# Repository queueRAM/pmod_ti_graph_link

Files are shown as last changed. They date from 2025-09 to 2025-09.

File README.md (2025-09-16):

# Pmod TI Graph Link breakout board

This repository contains a schematic and PCB layout for a [Pmod](https://digilent.com/reference/pmod/specification)-compatible design that interfaces with TI graphing calculators and peripherals which use the 2.5mm TI graph link connector. The purpose of the board is make it convenient to connect to the calculator DBus without having to solder a cable, provide a convenient pin-out, and to translate the bus voltage to support 3.3V and 5V. The Pmod connectors are very common with FPGA development boards. The board is generic and can be used with any circuit in the 3.3-5V range, such as Arduinos, Raspberry Pis, or homebrew 6502 on breadboards.

The 6-pin Pmod connector supplies VCC, GND, and the two bi-directional tip and ring connections. For each tip and ring there are pull-up resistor, diode, and NPN transistor to allow interfacing with buses of different voltages and out to a 2.5mm stereo TRS jack. The board provisions for an LC low-pass filters for each tip and ring, similar to what is used in the USB silver graph link, TI keyboard, and TI graphing calculators. For debug, the layout provisions for an optional 1x3 header on the DBus side.

## Design

The design optimizes for performance and cost while still being something that
can be hand-soldered. The passives are 0805 or larger, through-hold connectors
were chosen where possible. The diode and transistor are on the smaller pitch,
but were chosen to combine dual components into a single package.
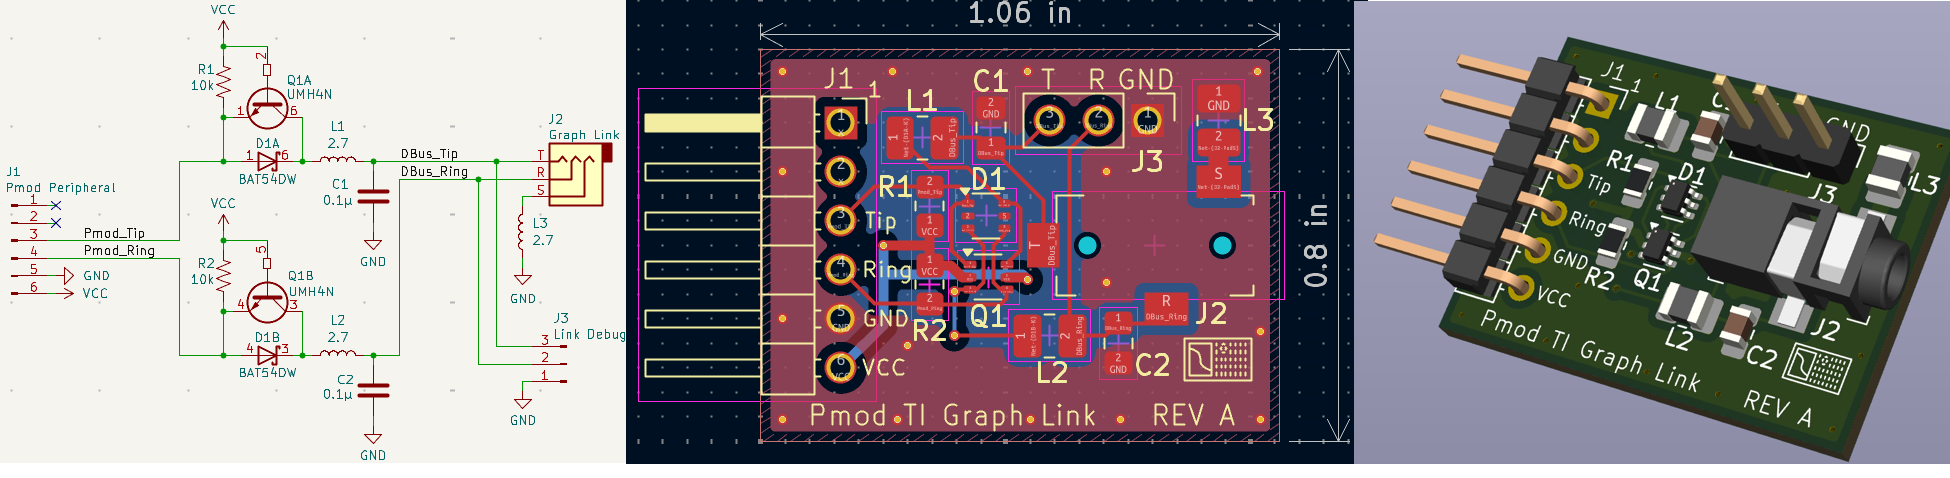
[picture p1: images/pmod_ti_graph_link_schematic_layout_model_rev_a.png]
Pmod TI graph link Rev A


## Bill of Materials (BOM)

REF DES | Footprint | Type            | Manufacturer | Part #           |Qty|
--------|-----------|-----------------|--------------|------------------|---|
J1      | Pmod 0.1" | Pmod Connector  | METZ         | PR20206HBNN      | 1 |
J2      | Custom    | 2.5mm TRS audio | Kycon        | STX-2500-3NTR    | 1 |
J3      | 0.1"      | Debug header*   | METZ         | PR20203VBNN      | 1 |
Q1      | SOT-363   | Bias transistor | Toshiba Semi.| RN1911,LF        | 1 |
D1      | SOT-363   | Schottky diode  | Panjit       | BAT54DW_R1_00001 | 1 |
R1,R2   | 0805      | Pull-up Res.    | YAGEO        | RC0805JR-1310KL  | 2 |
C1,C2   | 0805      | Capacitor*      | YAGEO        | CC0805KRX7R9BB104| 2 |
L1,L2,L3| 1008      | Inductor*       | TDK          | NLV25T-2R7J-EF   | 3 |

(* denotes optional)

 ## Notes

 * [Digilent Pmod specification](https://digilent.com/reference/_media/reference/pmod/pmod-interface-specification-1_3_1.pdf)
 * [TI Graph Link Hardware Protocol](https://www.merthsoft.com/linkguide/hardware.html)
 * [Pmod TI graph link Cemetech forum post](https://www.cemetech.net/forum/viewtopic.php?t=20602)

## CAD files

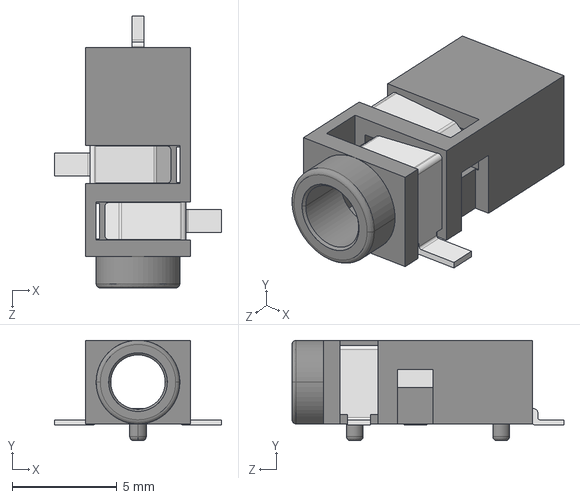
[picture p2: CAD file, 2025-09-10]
3dmodels/STX-2500-3N_rA3.IGS
8.00 x 4.80 x 13.0 mm

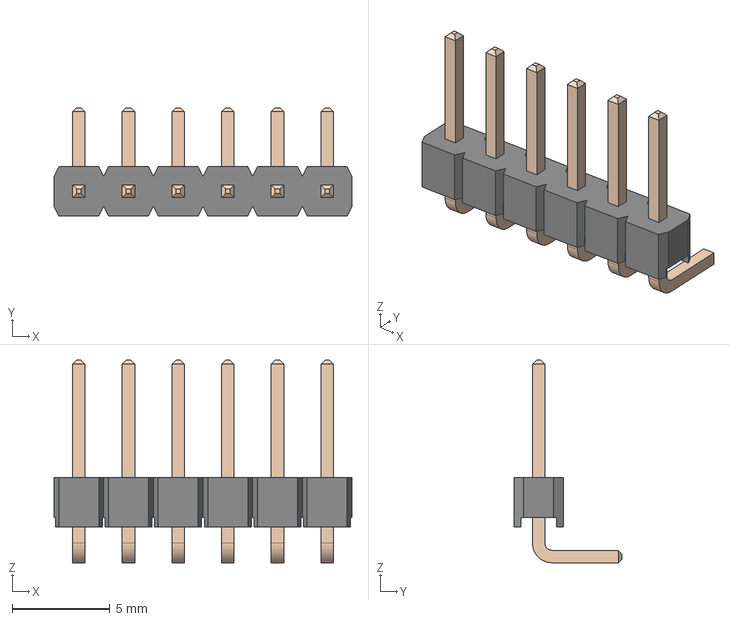
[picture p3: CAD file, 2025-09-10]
3dmodels/61300611021_rev1.stp
15.2 x 5.54 x 10.4 mm
6130xx11021_PIN x 6

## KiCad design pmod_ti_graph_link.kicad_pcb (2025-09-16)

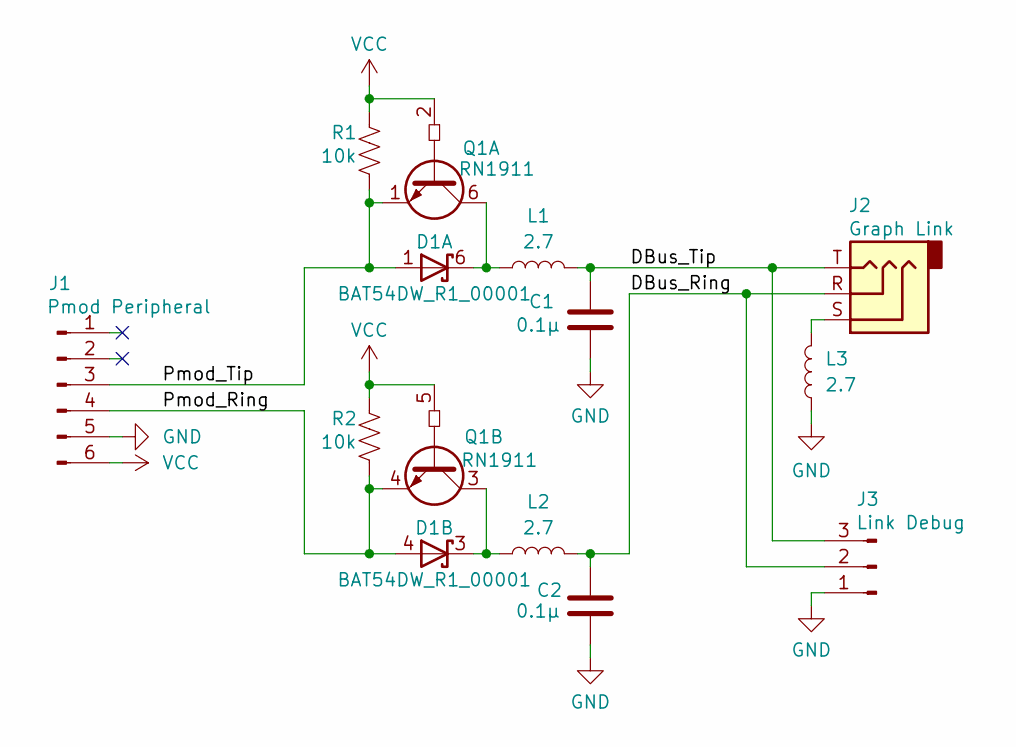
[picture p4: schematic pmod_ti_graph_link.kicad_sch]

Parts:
C1, C2: 0.1µ; C_0805_2012Metric_Pad1.18x1.45mm_HandSolder; Digikey 311-1140-1-ND
D1: BAT54DW_R1_00001; SOT-363_SC-70-6; Digikey 3757-BAT54DW_R1_00001CT-ND
J1: Pmod Peripheral; Pmod_1x06_P2.54mm_Horizontal; Digikey 1849-PR20206HBNN-ND
J2: Graph Link; Headphone_Jack_2.5mm_STX-2500-3NTR; Digikey 2092-STX-2500-3NTRCT-ND
J3: Link Debug; PinHeader_1x03_P2.54mm_Vertical; Digikey 1849-1003-ND
L1, L2, L3: 2.7; L_1008_2520Metric_Pad1.43x2.20mm_HandSolder; Digikey 445-16474-1-ND
Q1: RN1911; SOT-363_SC-70-6; Digikey RN1911LF(CTCT-ND
R1, R2: 10k; R_0805_2012Metric_Pad1.20x1.40mm_HandSolder; Digikey 13-RC0805JR-1310KLCT-ND

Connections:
/DBus_Ring: C2.1, J2.R, J3.2, L2.2
/DBus_Tip: C1.1, J2.T, J3.3, L1.2
/Pmod_Ring: D1.4 (A), J1.4, Q1.4 (E2), R2.2
/Pmod_Tip: D1.1 (A), J1.3, Q1.1 (E1), R1.2
GND: C1.2, C2.2, J1.5, J3.1, L3.1
unnamed: D1.6 (K), L1.1, Q1.6 (C1)
unnamed: D1.3 (K), L2.1, Q1.3 (C2)
unnamed: J2.S, L3.2
VCC: J1.6, Q1.2 (B1), Q1.5 (B2), R1.1, R2.1

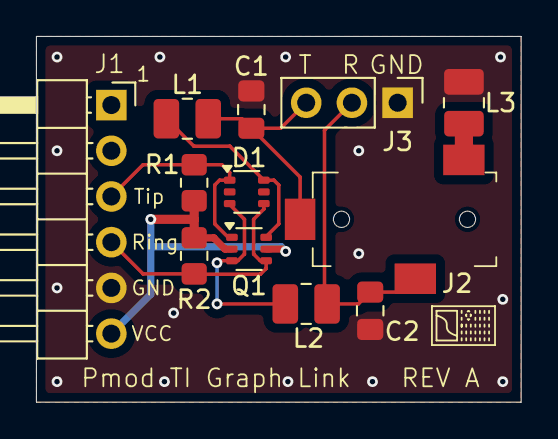
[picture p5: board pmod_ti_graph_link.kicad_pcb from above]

Board: 2 copper layers, 26.9 x 20.3 mm, 12 parts (0 on the bottom side), 9 nets.

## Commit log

2025-09-10 Initial commit of Pmod board for TI graph link
    - Adds 6-pin Pmod connector to 2.5mm TRS stereo audio
    - Uses biased transistor and diode for level translation
    - Optional LC filter and debug header
    [61300611021_rev1.stp, STX-2500-3N_rA3.IGS, pmod_ti_graph_link.kicad_pcb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]
2025-09-11 Clean up routing, add GND vias, add text
    - Clean up routing around transistor and diode
    - Add stitching GND vias around perimeter
    - Add "Pmod TI Graph Link" text and date
    [pmod_ti_graph_link.kicad_pcb, pmod_ti_graph_link.kicad_sch]
2025-09-12 Add inductor shield->GND and clean up placement and routing. Prelim "Rev A"
    - Add optional inductor between 2.5mm shield and GND
    - Make VCC thicker, update calc icon, clean up traces
    [pmod_ti_graph_link.kicad_pcb, pmod_ti_graph_link.kicad_sch]
2025-09-16 Add part numbers, README, and images of schematic/PCB/model
    - Add README detailing the project scope and BOM
    - Add image with screenshot of schematic, PCB, and 3D model
    - Specify solder mask and ENIG finish
    - Add Digikey part numbers for reference
    [pmod_ti_graph_link.kicad_pcb, pmod_ti_graph_link.kicad_sch]
